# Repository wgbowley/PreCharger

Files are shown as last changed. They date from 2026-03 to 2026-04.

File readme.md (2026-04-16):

### Pre-Charger circuit (recruit project)

Thank you for checking out my "side quest" into high voltage prechargers. It was generally a joy, and the elegance of some of these designs is truly exceptional. 
I had never really considered HV as a possible domain of exploration. However, after breaking down this problem, or more specifically the need for either active or passive chargers, that changed.
I have come to appreciate the idiosyncrasies of the domain, and honestly, it really was quite a pleasure. I have not validated or checked my work within this repo due to time constraints from other commitments, 
but feel free to reach out if I made a horrendous leap in judgment (probably due to bad assumptions).

Funny enough, I did not want to be highly abstract with this project. But when I was playing around with schematics in my notebook, 
I thought, "Holy! I can use this for version 2 of the coil launcher" because it needs a constant current or a passive pre-charger.
Man, I love abstractions. Nevertheless, thank you for reading, and I hope you find the work here useful.

# Credits:

### Research & Development Enabled by:
* [Texas instruments](https://www.ti.com/) - Thank you. That floating reference logic is literally so eloquent. I was smiling from ear to ear when I understood it.
* [RMIT RACE TEAM](https://www.rmitmotorsport.com/) - Generally, independent of the outcome of my time as a recruit, this was quite uplifting compared to motor design.

### Bibtex Citation:

```
@misc{Bowley_2026,
  author = {Bowley, William},
  title = {{PreCharger}},
  url = {https://github.com/wgbowley/PreCharger},
  year = {2026},
  note = {GitHub repository},
  license = {MIT}
}
```

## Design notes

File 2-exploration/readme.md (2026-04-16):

### Hybrid pre-charger circuit (recruit project)

Objective:
- To design a 600V active pre-charger circuit
- To ensure the design meets the requirements set by `saea` 
- To validate assumptions via analytical methods and lump-parameter simulation 
- To compare RC pre-charger with active pre-charger and define usage boundaries

## Report (Quite abstract): [Active vs Passive Pre-chargers](docs\raws\charger_report.tex)

Thank you for checking out my "side quest" into high voltage prechargers. It was generally a joy, and the elegance of some of these designs is truly exceptional. 
I had never really considered HV as a possible domain of exploration. However, after breaking down this problem, or more specifically the need for either active or passive chargers, that changed.
I have come to appreciate the idiosyncrasies of the domain, and honestly, it really was quite a pleasure. I have not validated or checked my work within this repo due to time constraints from other commitments, 
but feel free to reach out if I made a horrendous leap in judgment (probably due to bad assumptions).

Funny enough, I did not want to be highly abstract with this project. But when I was playing around with schematics in my notebook, 
I thought, "Holy! I can use this for version 2 of the coil launcher" because it needs a constant current or a passive pre-charger.
Man, I love abstractions. Nevertheless, thank you for reading, and I hope you find the work here useful.

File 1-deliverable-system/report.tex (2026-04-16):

\documentclass{article}
\usepackage{graphicx}
\usepackage{float} 

\title{Tractive System Pre-charger Module (First Draft)}
\author{William Bowley (S4226716) | Recruit Power Train}
\date{\today}

\begin{document}
\maketitle

\section{Overview}
The pre-charge module exists to mitigate inrush current when the accumulator is connected to the 
tractive system. This is because of the existence of a large bulk capacitance placed in parallel 
with the accumulator to manage line transients from large dynamic current sinks like the motors.

\vspace{0.5cm}
The high-level system architecture was predefined by the system leads to be based on a passive RC 
(resistor \& capacitor) circuit because start-up isn't a competition criterion and hence increasing 
$\tau$ to expand the duration of the current pulse is optimal and it increases margins. Most importantly, 
the passive pre-charger is extremely reliable due to minimal failure points compared to alternatives.

\vspace{0.5cm}
The pre-charge sequence is as follows: the negative HV contactor connects the accumulator negative terminal to the
system reference. The pre-charge contactor then is allowed to close, which enables current flow through the 
pre-charge resistor into the DC link capacitance. Once the DC link voltage approaches the accumulator voltage
approximately 3$\tau$, the main positive contactor is closed. The pre-charge contactor is subsequently opened
to remove the series resistance from the power path. 

\section{Constraints}

Solid-state relays or FETs are not allowed due to RE.5.6.5 `The pre-charge relay must be a mechanical type relay'
hence a mechanical relay will be used as the pre-charge contactor. All components that dissipate heat must be 
monitored for thermal overload. The PDOC must open the shutdown circuit before exceeding the maximum operating temperature.
However, due to this design being validated to run continuously even in a faulted state, the PDOC can be omitted.

\vspace{0.5cm}
Importantly, the mechanical relay must be normally open such that if shutdown (SDC) is low, the accumulator must be disconnected
from the tractive system. 

\section{Detailed Design}
The PWR263S-35 power resistor was chosen due to its 35 W rating and its package being suitable for SMD (TO-263). It was decided that
using a few resistors in series would be better as they distribute the heat. The KT24-1A-40L-SMD mechanical switch was
chosen because of its 1 A continuous current rating and low coil resistance of 150 to 200 m$\Omega$.

\vspace{0.5cm}
The activation time was arbitrarily set to 4.5 s which at a 3$\tau$ requirement resulted in 6x1 k$\Omega$ resistors from `system\_stress.py'.
The maximal inrush current hence was $\sim$100 mA with 43.2 J being delivered to the DC link capacitor.

\vspace{0.5cm}
A worst case continuous fault leads to each resistor absorbing 10 W continuous which is $\sim$1/3.5 of their maximum rating.
The mechanical relay is 
connected to \texttt{pre\_aux\_out} \& \texttt{pre\_aux\_in} from the AMS main board to enable or disable it. With \texttt{prech\_coil\_pos} \&
\texttt{prech\_coil\_neg} supplying the current to activate the relay. This design reflects the R26 AMS architecture. 

\vspace{0.5cm}
A 4 pin XH 2.54 mm JST connector was selected due to it being the standard for a low voltage application like the AMS connection to pre-charger. A Molex
connector was used for the input and output of the HV line specifically a Molex Mini-Fit Jr which is rated for 600 V while having a reasonable form factor.
However it is a 4 pin connector hence only 2 pins are used which are orthogonal to each other. The trace width is set to 0.80 mm and the trace spacing is
1.25 mm for both low voltage and high voltage components.

\section{Conclusion}
The design proposed here should function correctly under standard operating conditions. Images and data-sheets can be found within `1-deliverable-system'.
The Bourns PWR263S-35-1001F resistor should have a significant safety margin for both power dissipation (10 W vs 35 W) and operating voltage (600 V vs 700 V).

By designing a series-string passive pre-charger, the thermal load is distributed across the PCB. Furthermore, the integration of a mechanical reed relay 
ensures full compliance with Rule RE.5.6.5, providing the required isolated fail-safe state when the shutdown circuit is de-energized. This approach
balances the robust and reliable requirements of a tractive system and also the strict safety constraints.

\section{Bill of Materials}
\begin{table}[H]
\centering
\caption{Estimated Component and Manufacturing Costs (AUD)}
\begin{tabular}{|l|l|c|c|r|}
\hline
    \textbf{Component} & \textbf{Part Number} & \textbf{Qty} & \textbf{Unit Price} & \textbf{Total} \\ \hline
    Power Resistor (1k$\Omega$) & Bourns PWR263S-35-1001F & 6 & \$5.15 & \$30.90 \\ \hline
    Reed Relay & Standex KT24-1A-40L-SMD & 1 & \$8.40 & \$8.40 \\ \hline
    HV Header (4-pin) & Molex Mini-Fit Jr (39-29-1048) & 2 & \$1.70 & \$3.40 \\ \hline
    LV Header (4-pin) & JST XH (B4B-XH-A) & 1 & \$0.21 & \$0.21 \\ \hline
    PCB Manufacturing & Custom 2-Layer Board & 1 & \$10.00 & \$10.00 \\ \hline
    \multicolumn{4}{|l|}{\textbf{Subtotal}} & \textbf{\$52.91} \\ \hline
\end{tabular}
\end{table}

\end{document}

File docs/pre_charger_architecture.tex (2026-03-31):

\documentclass{article}

\begin{document}

\section{Introduction}
This document compares the RC time circuit pre-charger with a buck converter style active pre-charger for the 
RMIT racing car battery pack.

\section{RC Time Circuit Pre-Charger [1]}
The RC time circuit pre-charger is a simple and redundant design that uses a resistor and capacitor to limit the inrush current when connecting the battery
pack to the high voltage system. The RC time constant itself is a fundamental property of the discrete components used in the circuit, though can be affected
by parasitic capacitance and resistance in the circuit. However compared to the expected value of the 1-4.2k$\Omega$ resistor and 100-1000$\mu$F capacitor, 
the parasitic effects are most negligible if reasonable considerations are taken.

\vspace{0.5cm}
The RC circuit is feed by the high voltage (HV) system via a relay that closes the circuit to charge the DC linked capacitor and than the main relay is closed to
connect the battery pack to the high voltage system. This ensure that no high inrush current is experienced by the main relay, which can cause damages it. And also components
down the line due to di/dt coupling between HV and low voltage (LV) systems. It also ensures that the DC linked capacitor is not damaged due to the inrush either. Main 
fault mode of this design seems to be relay failure or pulse power failure, which is inherent to any HV system, so not architecture specific.

\section{Buck Converter Style Active Pre-Charger [2]}
This design uses a buck converter style active pre-charger to limit the inrush current when connecting the battery pack to the HV system. This design is inherently more complex
due to its control scheme and additional components (failure points) but can be in a smaller form factor, can hit the 90\% voltage target faster and lastly removes mechanical wear due
to its solid state design. It also allows for current limiting, tuning and telemetry capabilities that the RC time circuit pre-charger doesn't have by default.

\vspace{0.5cm}
The control scheme is based on a voltage feedback loop that adjusts the duty cycle of the buck converter to maintain a constant voltage across the DC linked capacitor. However the design
is more similar to a LC circuit due the inclusion of a power inductor in-series with the dc link capacitor. The resistor is mainly a shunt resistor for measuring line current, but given
that inductive elements have resistance, the most accurate comparison is a switch-mode driven LRC circuit. Texas instruments reference design uses a comparator for current measuring 
across the shunt and a n-channel FET for switching. Though its not clear if the design uses the FET only during pre-charging or if it is used as the main switch as well. If the FET is used
as the main switch, it can be even more compact than the RC time circuit pre-charger, but it becomes a single source of failure for the entire system. The main fault mode of this design seems
to be the FET failure, which can leave the HV system active even when the systems should be disabled.

\section{Conclusion}
The RC time circuit pre-charger is a simple and redundant design that is less likely to fail due to its simplicity, but the active approach can be more compact, faster and have more features.
Due to the SAE being a mix competition, the active system can be more beneficial due to the tuning capabilities and points scored during the design event, but the RC time circuit pre-charger
is the easier to ship fast but has less points potential. The final decision really is up to wether the team values potential points or freeing up time for other systems more. Specifically
testing this subsystem due to the nature that this isn't a conceptually difficult nor untested technology, but it needs to be proven to work before any integration.

\vspace{0.5cm}
Due to my position as a recruit, I don't have the full picture of the team's priorities and resources but I do have time to investigate this as a possible future inclusion, So I will design and 
computationally validate the design of an active pre-charger circuit as a reference for future work by myself or others. This will be done mainly through LTSPICE, equivalent circuit modelling
and analytical calculations. I will also design a test bench for the active pre-charger encase the team decides to go with this design in the future, but I won't be able to build it due to time 
constraints placed by other personal commitments. 

\begin{thebibliography}{5}

\bibitem{ti_brief} 
\textit{Why Pre-Charge Circuits are Necessary in High-Voltage Systems}, Texas Instruments, Jan. 2023. [Online]. Available: \url{https://www.ti.com/lit/ab/slvafb0/slvafb0.pdf}

\bibitem{ti_ref} 
\textit{High-Voltage Solid-State Relay Active Pre-charge Reference Design (TIDA-050063)}, Texas Instruments, Jan. 2023. [Online]. Available: \url{https://www.ti.com/tool/TIDA-050063}

\end{thebibliography}

\end{document}

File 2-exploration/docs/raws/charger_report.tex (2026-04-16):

\documentclass{article}
\usepackage{graphicx}
\usepackage{float} 

\title{Active and passive pre-chargers (First Draft)}
\author{William Bowley (S4226716) | Recruit Power Train}
\date{\today}

\begin{document}
\maketitle

\section{Overview}
This document begins with a comparison between the RC and active bang-bang pre-charger circuits, specifically scaling laws using a stress index function that includes current, power, and time.

\vspace{0.5cm}
Then, the architecture choice is based on scaling laws and the future modularity of the system given changes in system dynamics. After which, the chosen architecture will be simulated in 
LTspice and then modelled in Altium Designer. Lastly, validation of the schematic and PCB will be done using analytical methods.

\section{Architectural choices}
An RC time constant pre-charger is a simple and redundant design that uses a resistor and capacitor to limit the average current, but does exhibit a high initial peak current. The RC 
time constant itself is a fundamental property of the discrete components used in the circuit, though it can be affected by parasitics. The RC circuit is fed by the high voltage battery 
system via a relay that closes the circuit to begin the charging period. The current and voltage both follow an exponential curve, with the total time constant being some multiple of the 
$\tau$ constant depending on the required charge level.

\vspace{0.75cm}
The bang-bang pre-charger circuit is a more complex design, less redundant, but can charge faster without large initial peak currents. It uses a constant current to charge the DC link capacitor
 with an inductor and resistor in series. The inductor feeds the capacitor over time, increasing its energy state. The resistor is a shunt resistor that is used to measure the current by the comparator, 
 which modulates the input to the FET driver.

\section{Scaling laws}

Each architecture is quite different and therefore hard to compare, which in itself presents an interesting problem due to that fact. This report uses a stress index function, which, as stated in the 
overview, uses peak current, power loss across the resistor, and charge time as stress factors. The following equations were formed to describe this relation:

% Passive Stress Equation
\begin{equation}
S_{passive} = \frac{V}{R \cdot i_{\max}} + \frac{V^2}{10R \cdot p_{\max}} + \frac{5RC}{t_{\max}}
\end{equation}

% Active Stress Equation
\begin{equation}
S_{active} = \frac{i_{peak}}{i_{\max}} + \frac{P_{r}}{p_{\max}} + \frac{t}{t_{\max}}
\end{equation}

\vspace{0.5cm}
These stress functions are a mix of simulation and analytical results. Due to the passive charger's simplistic architecture, the passive stress equation could be derived analytically, whereas the 
active stress equation had to be modelled using a second order current model and solved with the Ralston method. The following weighting parameters were used to stabilize the results both in magnitude and dimensionality. 

\begin{table}[H]
\centering
\begin{tabular}{|l|c|c|c|}
\hline
\textbf{Parameter} & \textbf{Symbol} & \textbf{Passive} & \textbf{Active} \\ \hline
Capacitance        & $C$             & $240\,\mu\text{F}$    & $240\,\mu\text{F}$   \\ \hline
Resistance         & $R$             & $1\,\text{k}\Omega$   & $40\,\Omega$         \\ \hline
Input Voltage      & $V$             & $600\,\text{V}$       & $600\,\text{V}$      \\ \hline
Inductance         & $L_1$           & N/A                   & $560\,\mu\text{H}$   \\ \hline \hline
Max Current        & $i_{\max}$      & \multicolumn{2}{c|}{1 A}                     \\ \hline
Max Power          & $p_{\max}$      & \multicolumn{2}{c|}{25 W}                    \\ \hline
Max Time           & $t_{\max}$      & \multicolumn{2}{c|}{5 s}                     \\ \hline
\end{tabular}
\caption{System Operating Parameters}
\end{table}

Using those parameters, a series of different sweeps were run to understand the scaling relationship between the different variables, specifically capacitance, resistance, and operating voltage. 
An important consideration is that the absolute magnitude is not strictly important. Rather, the scaling rate is most important, similar to Big O notation in computer science.

\begin{figure}[H]
    \centering
    \begin{minipage}{0.48\textwidth}
        \centering
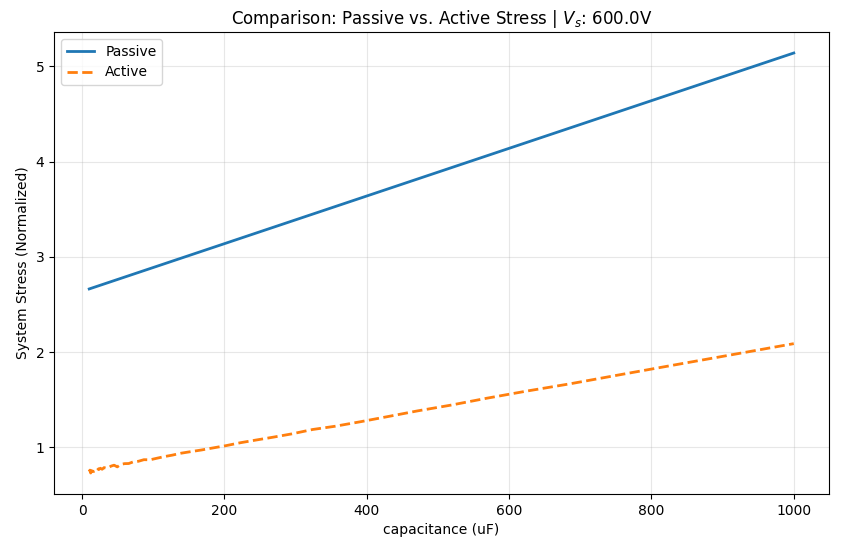
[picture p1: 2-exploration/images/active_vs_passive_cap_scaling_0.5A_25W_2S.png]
        .png}
        \caption{Capacitance Scaling in linear space}
    \end{minipage}
    \hfill
    \begin{minipage}{0.48\textwidth}
        \centering
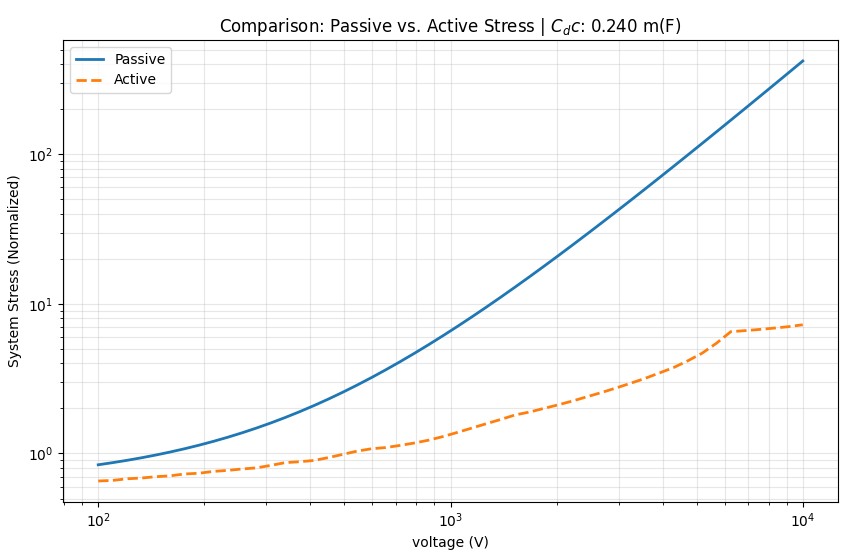
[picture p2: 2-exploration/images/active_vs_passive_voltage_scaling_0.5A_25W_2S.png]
        .png}
        \caption{Voltage Scaling in log-log space}
    \end{minipage}
\end{figure}

As can be seen in Figure 1, increasing capacitance linearly increases system stress. Hence, the relationship is directly proportional. This is true for both systems. In Figure 2, 
the voltage scaling is less clear, but it appears both systems increase quadratically in log-log space. This can be explained by the quadratic relationship between a capacitor's energy and its voltage. 
Interestingly, the active pre-charger in both cases seems to have a lower gradient and stress intercept, but this is most likely specific to the static parameters or favourable weighting. 
The flat section of the graph for the active pre-charger in Figure 2 is not a numerical artifact.

\begin{figure}[H]
    \centering
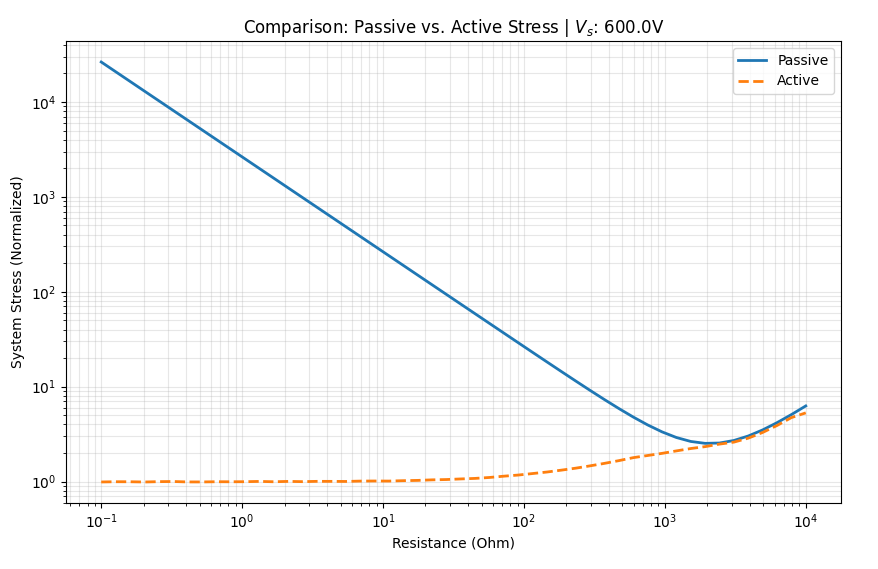
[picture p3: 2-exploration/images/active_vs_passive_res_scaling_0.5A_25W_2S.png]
    .png}
    \caption{Resistance Scaling Comparison in log-log space}
\end{figure}

Figure 3 shows where the active pre-charger might have an advantage, as its system stress is flat until the resistance limits the current below the hysteresis level, at which point the active system's duty cycle 
becomes 100\%. Interestingly, the passive pre-charger has decreasing system stress at higher resistance values until an inflection point. This inflection point occurs because the time constant ($\tau$) becomes larger 
than the stress contribution from $i_{\max}$ or $p_{\max}$.

\section{Architectural decision}

Given the scaling laws described above, the active system does not carry much technological weight, outside of possible lower gradients for voltage vs stress and capacitance vs stress. The active system does, 
however, have higher efficiency due to its much lower series resistance, and it also features lower peak currents due to active control. It also offers greater future system leverage due to its ability to charge a 
larger or smaller capacitor at the same rate, thereby decoupling the bulk DC capacitance from the design.

\vspace{0.5cm}
However, it does generate EMI, adds more failure points, and may violate regulations depending on implementation details. The passive pre-charger is simple to the point of offering major reliability, and due to this, 
is ideal for racing. It could be argued that its simplicity limits its use cases, which is true in more extreme designs. However, for a race car, an exponentially decreasing current peak is negligible compared to the 
transients from the inverters driving the motor, both in magnitude and duration. 

\vspace{0.5cm}
Lastly, the stress function implicitly favours the architecture that decreases charge time. However, for a race car, pre-charging the powertrain happens well before the timed event. Hence, it could be argued that 
$i_{\max}$ or $p_{\max}$ are the real contributing factors. Therefore, a passive charger could be considered applicable to non time constrained systems, whereas an active charger is applicable to time constrained systems. 

\vspace{0.5cm}
Given the analysis above, the most optimal configuration for a race car pre-charger is a passive system. This holds true until the boundary where $\tau$ is too high due to the need for higher resistance to limit current, 
combined with high capacitance. If start-up from a disconnected state were a required event, then an active system might be more optimal. So overall, the reasonable choice would be passive. However, due to my status as a 
recruit and this project being an on boarding exercise (sandbox), I personally would like to design the active charger on paper, even though it is not the most optimal choice for this application.

\section{Detailed design}

Design began with referencing the TIDA-050063 design guide by Texas Instruments and using the reference calculations to develop two programs: firstly, `bang-bang-comparator.py`, which calculates the resistors needed to 
measure the current flowing through the RLC circuit. The next program was `inductor-selection.py`, which aimed to select an inductor large enough to limit di/dt so that the comparator could control it via hysteresis, 
while still remaining within a reasonable operating frequency.

\vspace{0.5cm}
After those programs were run, an LTspice model was developed using the TLV7011 comparator and UCC27517 gate driver. Both of these ICs were used by TI in their reference design. Quite elegantly, TI used a floating reference 
(VSSS) to allow the UCC27517 to drive the high side FET. The E3M0160120K was chosen due to the lower current requirement of this design (0.2 to 1.0 A) compared to TI's ~8.0 A. Another benefit of this choice is a much lower gate 
charge, hence higher switching frequencies can be used.

\vspace{0.5cm}
Due to the floating reference, both the comparator and gate driver must be powered by an isolated gate supply, such as the TPSI3052QDWZRQ1 in the reference design. This led to a major hurdle, and ultimately derailed the timeline 
for delivering a schematic and PCB design in Altium. The LTspice model of the UCC27517 contained a hidden assumption that referenced net 0, essentially always grounding the floating plane. It cannot be overstated how influential
 this was to progress. However, it was not a vendor mistake. This gate driver model was most likely not expected to be used in a floating ground arrangement. Hence, the mistake lies squarely with me for not checking the model assumptions. 

\section{Next Steps}
The next step for this project is to replace the UCC27517 with a model compatible with floating grounds. Alternatively, a high side gate driver could be used, but this would shift the project from a known problem set into a more 
complex endeavour. On the circuit itself, the selection of the Schottky diodes and the inductor is still required. After that, modelling should continue in LTspice, if this work remains non iterative. If it is not just a paper design, 
then performing an initial iteration to collapse the design space and assumptions would most likely be worthwhile. 

\end{document}

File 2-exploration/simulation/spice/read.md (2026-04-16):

# LT-SPICE
- Simulation does not currently work because the gate driver SPICE model has hidden references to net 0. Hence when the VSSS can't floating up with the mosfet source.

### Improvements needed
- Replace the gate driver model with one that doesn't have hidden assumptions or you a different topology like a high side MOSFET.

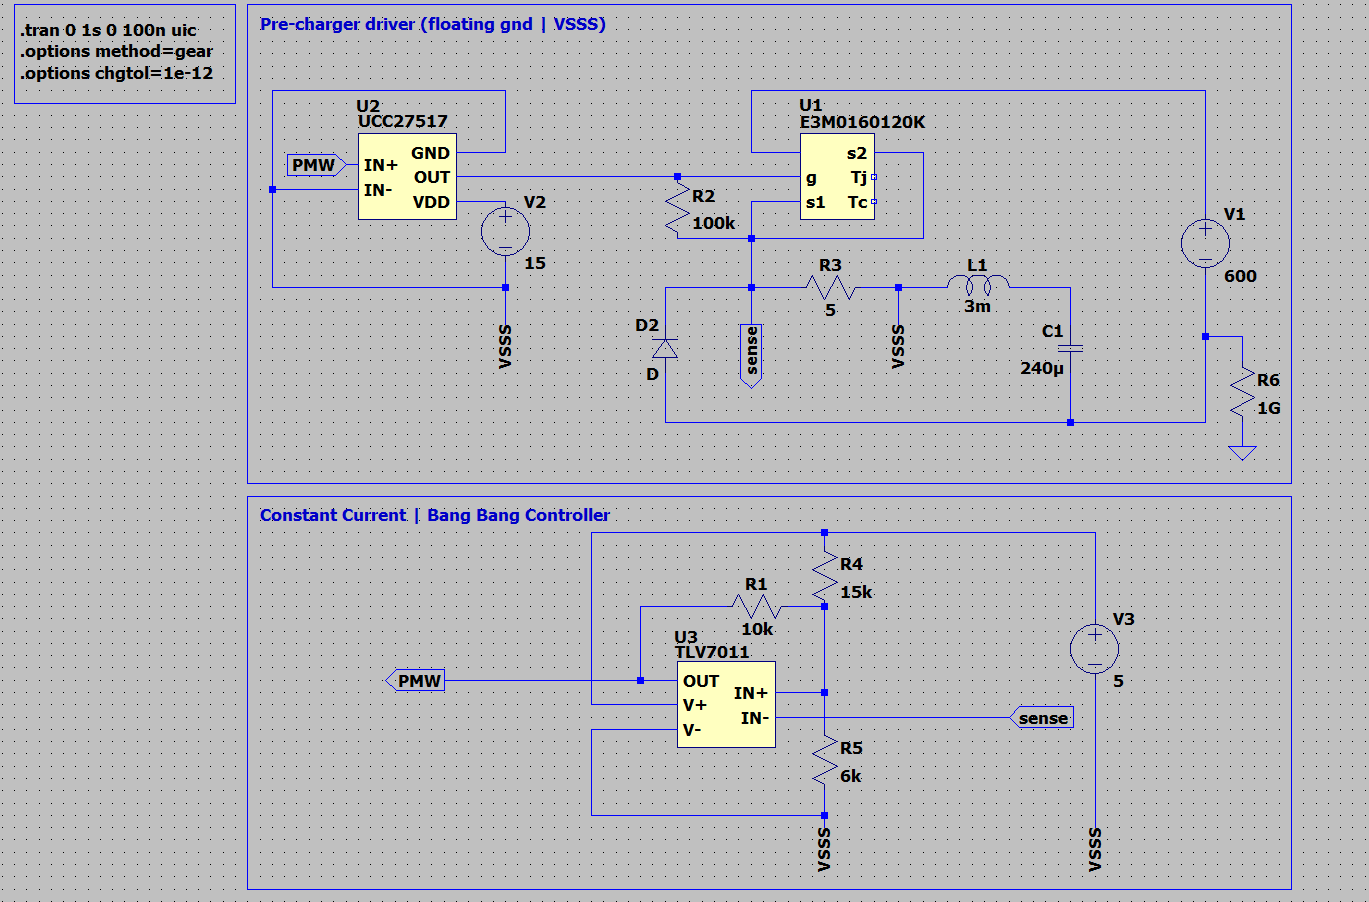
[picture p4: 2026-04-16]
2-exploration/images/schematic.png

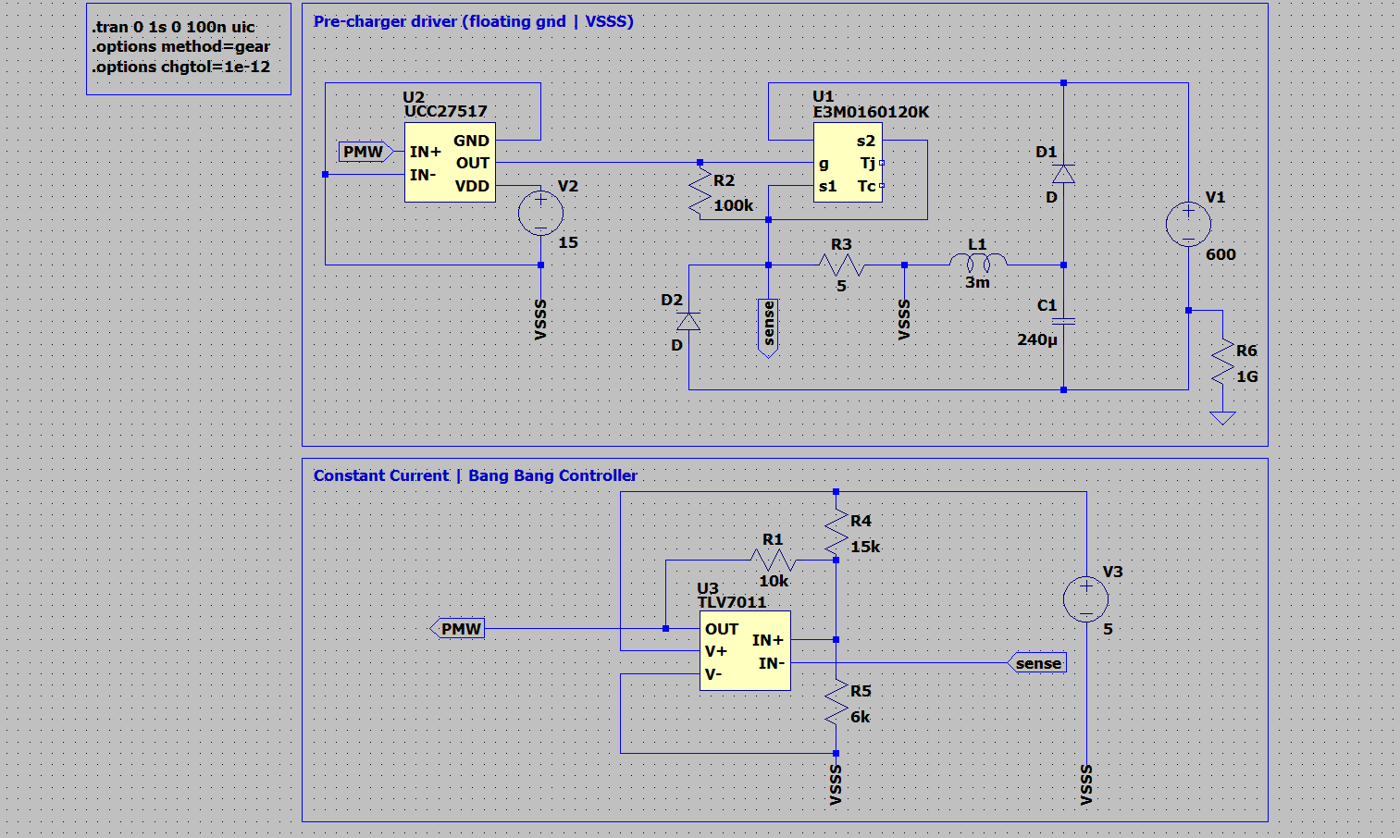
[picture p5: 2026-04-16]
2-exploration/images/circuit_schematic.png

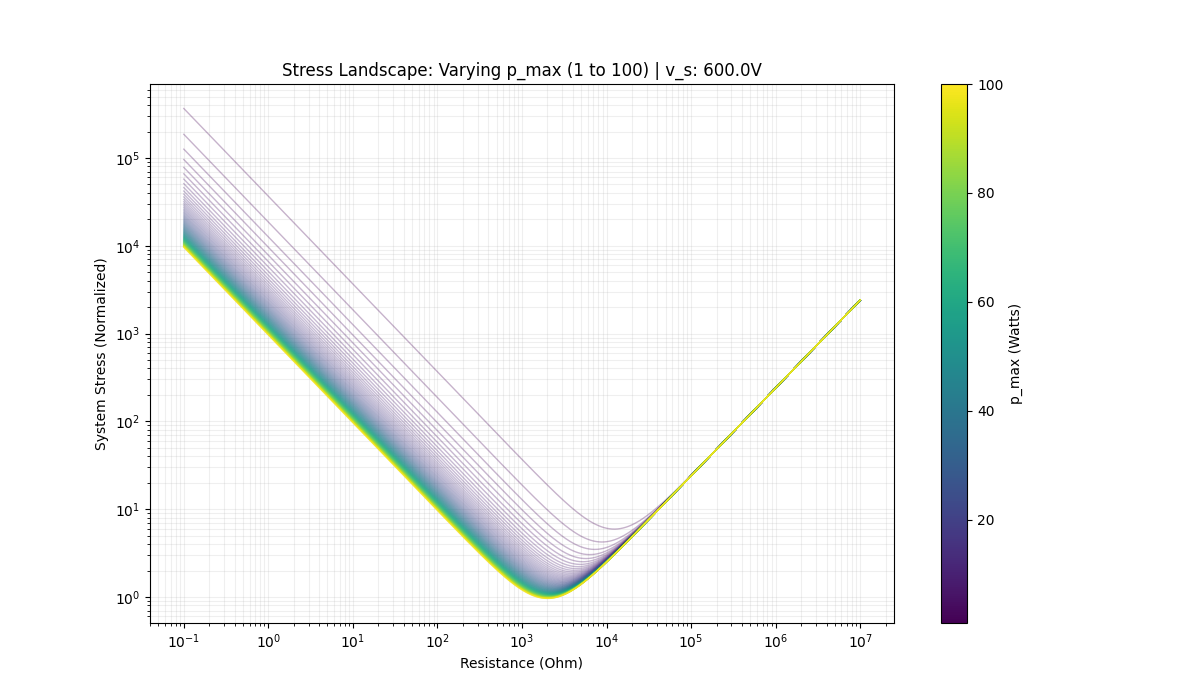
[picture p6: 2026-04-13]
2-exploration/images/cycling_through_p_factors_1A_5S.png

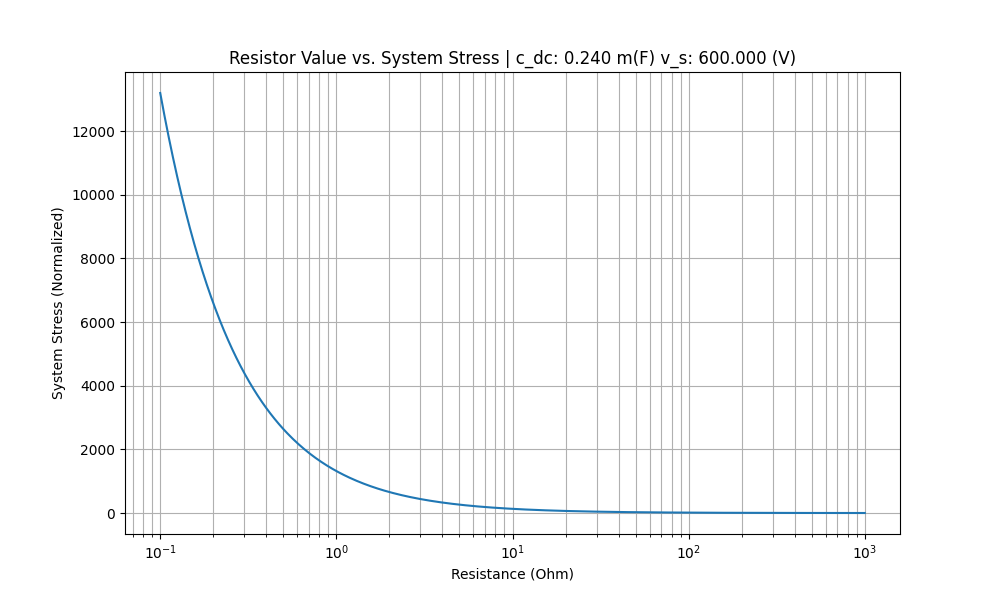
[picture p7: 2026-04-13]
2-exploration/images/stress_map_changing_resistance_without_time_1A_5S.png

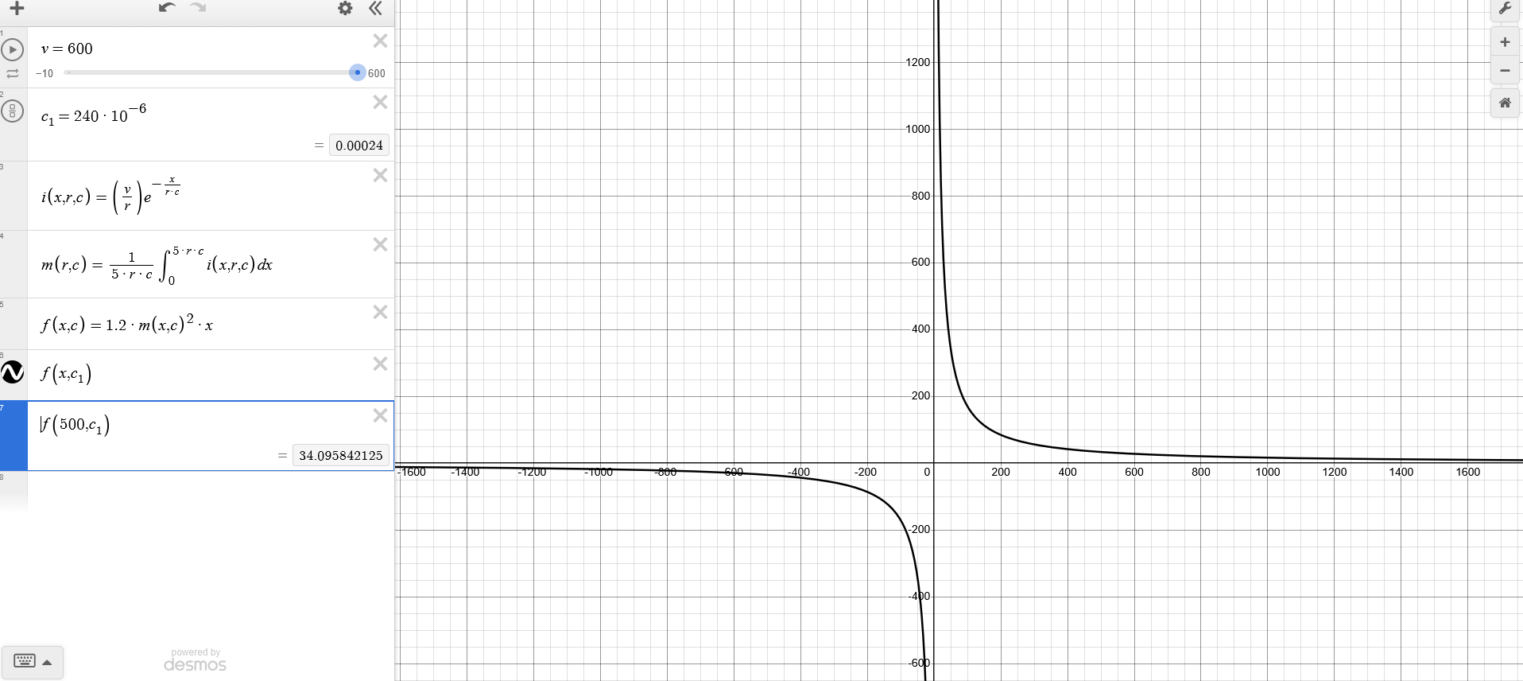
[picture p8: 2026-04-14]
2-exploration/images/passive_power_curves_desmos.png

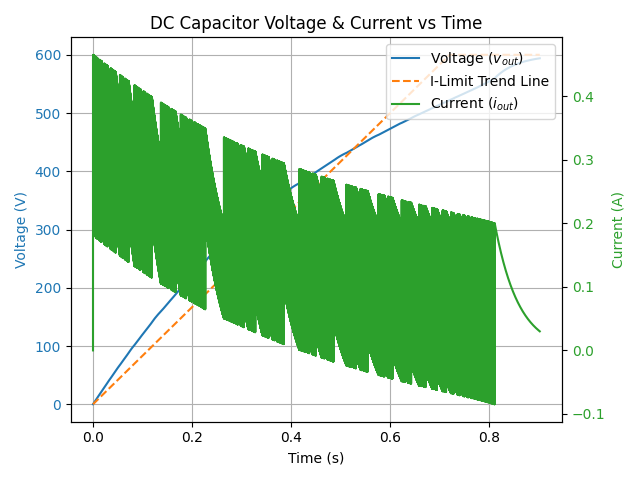
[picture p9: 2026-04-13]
2-exploration/images/bang-bang-controller.png

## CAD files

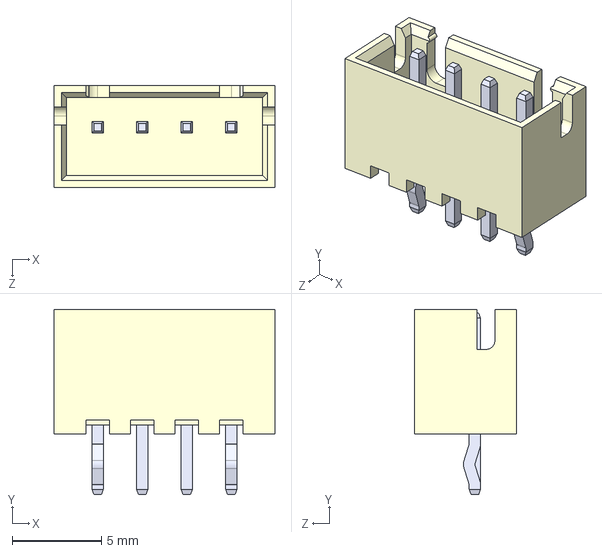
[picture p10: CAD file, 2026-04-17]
1-deliverable-system/precharger/components/B4B-XH-A_LF__SN_/B4B-XH-A_LF__SN_.step
12.4 x 10.4 x 5.75 mm

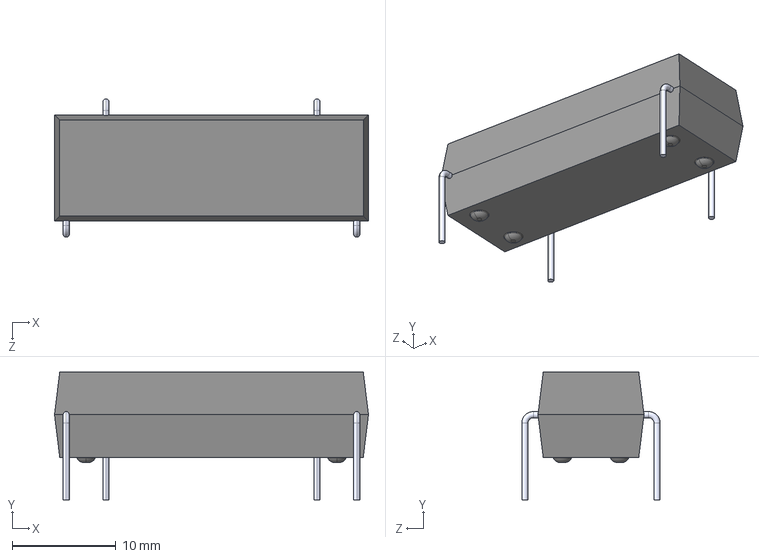
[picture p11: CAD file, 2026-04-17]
1-deliverable-system/precharger/components/KT12-1A-40L-THT/KT12-1A-40L-THT.step
30.2 x 12.3 x 13.3 mm

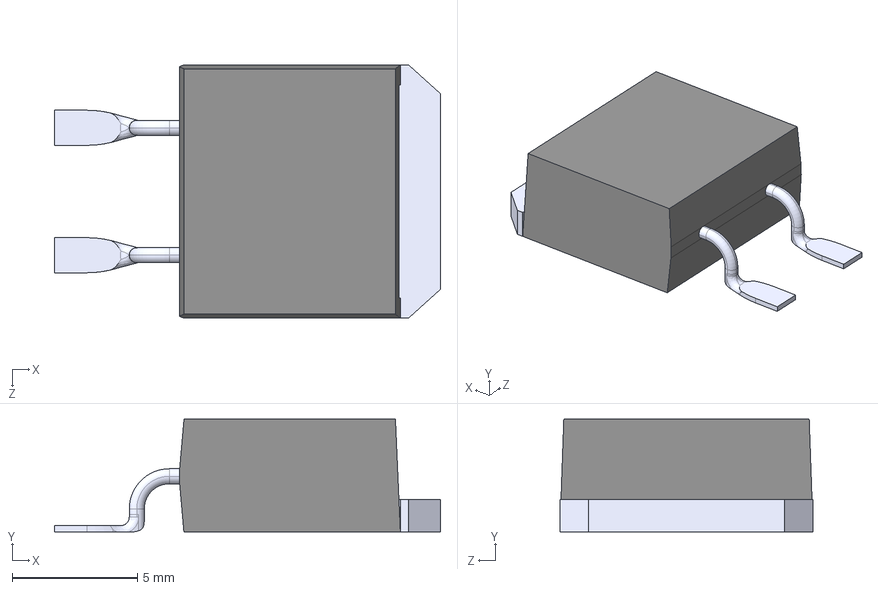
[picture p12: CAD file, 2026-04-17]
1-deliverable-system/precharger/components/PWR263S-35-1200FE/PWR263S-35-1200FE.step
15.4 x 4.50 x 10.1 mm

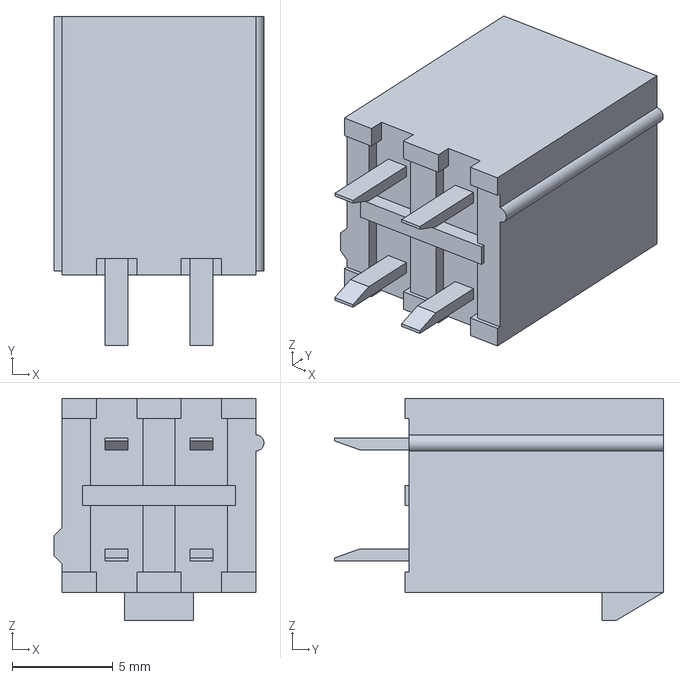
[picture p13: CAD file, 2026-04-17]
1-deliverable-system/precharger/components/Molex_Mini-Fit_Jr/39290043.step
10.4 x 16.3 x 11.0 mm

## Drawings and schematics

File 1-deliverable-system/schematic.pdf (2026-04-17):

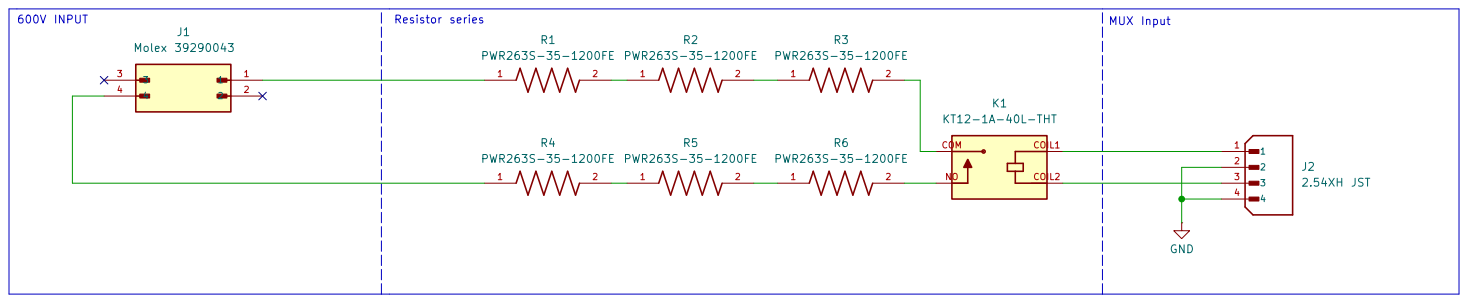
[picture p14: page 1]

Sheet: /
File: precharger.kicad_sch
Title: Series-String Passive Precharger

Size: A4 | Rev:
KiCad E.D.A. 10.0.0 | Id: 1/1

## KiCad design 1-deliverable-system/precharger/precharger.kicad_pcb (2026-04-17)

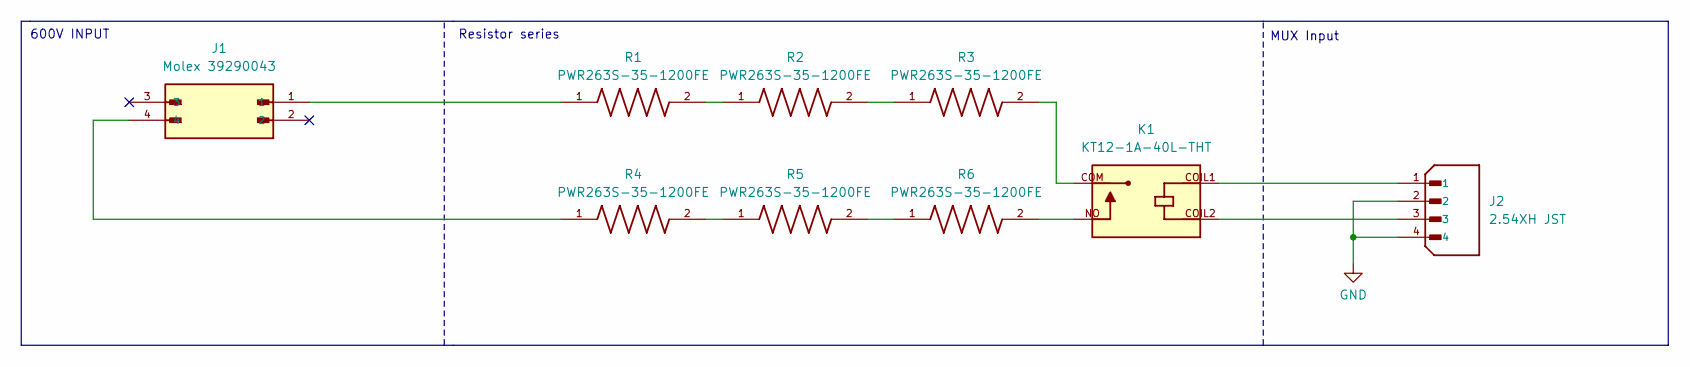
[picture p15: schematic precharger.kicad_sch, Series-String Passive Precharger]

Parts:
J1: Molex 39290043; MOLEX_39290043; PARTREV M4
J2: 2.54XH JST; JST_B4B-XH-A_LF__SN_; PARTREV 7/4/21
K1: KT12-1A-40L-THT; RELAY_KT12-1A-40L-THT; PARTREV 9
R1, R2, R3, R4, R5, R6: PWR263S-35-1200FE; RES_PWR263S-35-1200FE; PARTREV 12/20

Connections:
GND: J2.2, J2.4
unnamed: J1.1, R1.1
unnamed: J1.4, R4.1
unnamed: J2.1, K1.COIL1
unnamed: J2.3, K1.COIL2
unnamed: K1.COM, R3.2
unnamed: K1.NO, R6.2
unnamed: R1.2, R2.1
unnamed: R2.2, R3.1
unnamed: R4.2, R5.1
unnamed: R5.2, R6.1

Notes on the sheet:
600V INPUT
Resistor series
MUX Input

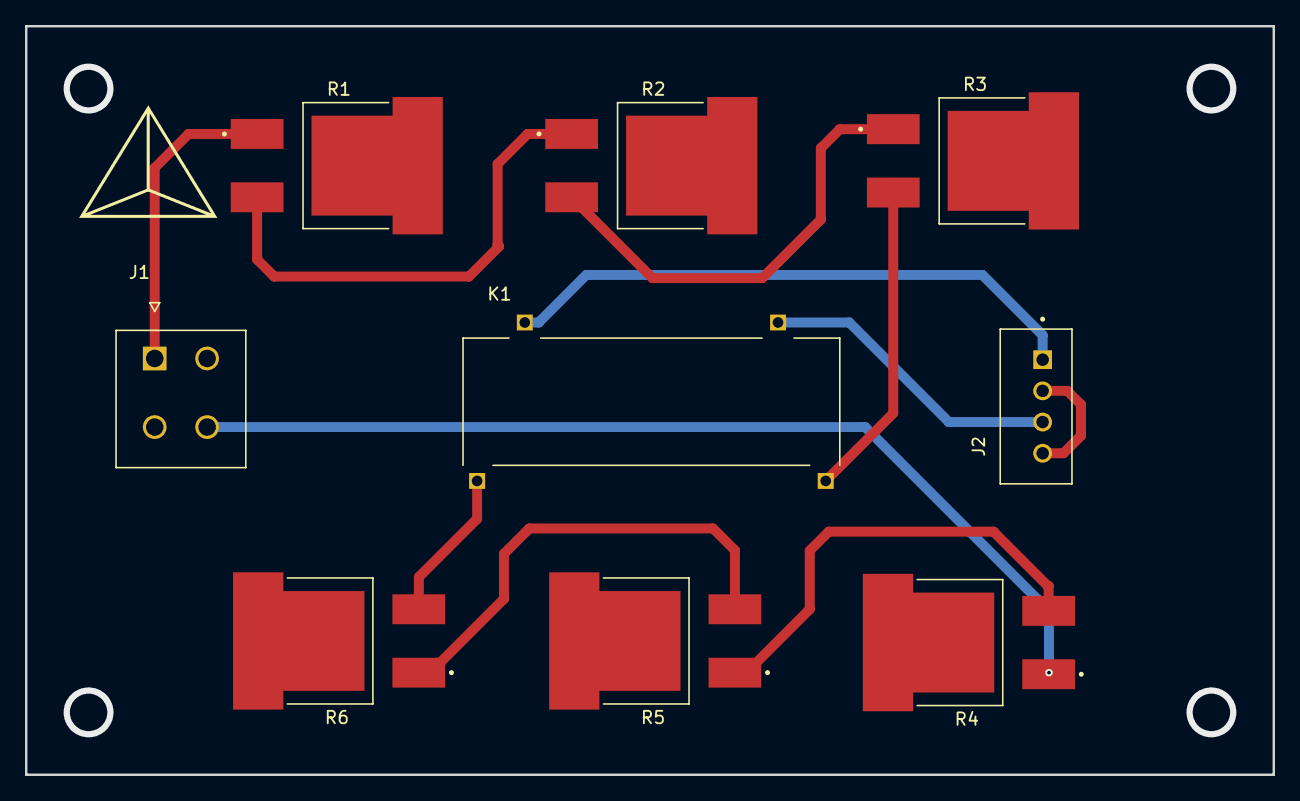
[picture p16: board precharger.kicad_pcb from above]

Board: 2 copper layers, 100.0 x 60.0 mm, 9 parts (0 on the bottom side), 11 nets.

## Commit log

2026-04-12 made a prototype lumped parameter simulation for better control of variables
2026-04-13 analytical model for active charger - finished
2026-04-16 write up & sign off :✌️:
    Plz be right
2026-04-16 structural change + series-string passive pre charger
2026-04-17 rough pcb design
    [39290043.step, B4B-XH-A_LF__SN_.step, KT12-1A-40L-THT.step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]
